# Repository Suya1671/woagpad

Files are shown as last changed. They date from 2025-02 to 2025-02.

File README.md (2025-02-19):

# The Woagpad

## A macropad of all time

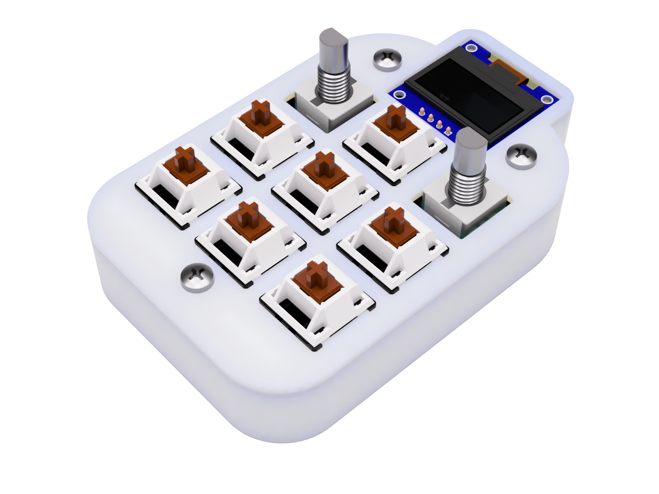
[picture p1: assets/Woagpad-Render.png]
Woagpad


The woagpad is a board I decided to create because a macropad
kinda just sounds fun. I really also wanted the rotary encoders
to be able to change volume and control media playback (although RMK doesn't support it yet. Eventually:tm:).

## Features

- **Rust based firmware**: Through the power of [RMK](https://haobogu.github.io/rmk), the firmware is written in 100% Rust. Crab gaming :crab:
  - [VIAL](https://get.vial.today/) support OOTB
- **128x64 OLED Display**: Display whatever the hell you want*
- **2 EC11 Rotary Encoders**: Control your volume or scroll through pages with these*
- **3x3 key matrix**: Keypad, macro, media controls, whatever the hell you want. You have 9 keys to mess around with (this includes the push buttons on the rotary encoders)

*The default rmk firmware does not support OLED display or rotary encoders yet.
Once those are implemented, the firmware will be updated to support them.
Write your own firmware to take advantage of these features!

## Design

### PCB
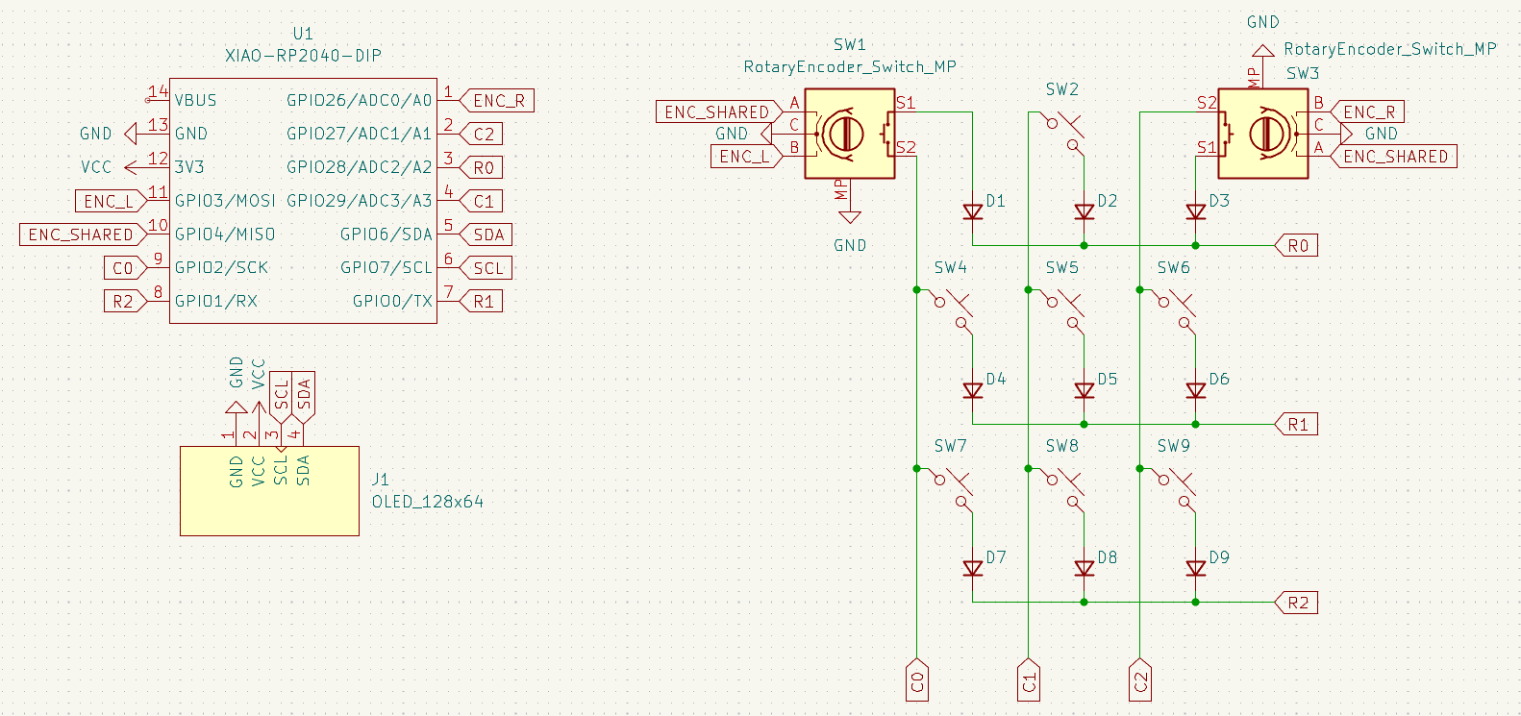
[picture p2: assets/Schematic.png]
Schematic


Bog standard PCB Schematic for a macropad.
This is actually my first design that uses a matrix
and an OLED display so that's fun.

Also yes, 2 encoders can share a pin! Neat.

|Front|Back|
|---|---|
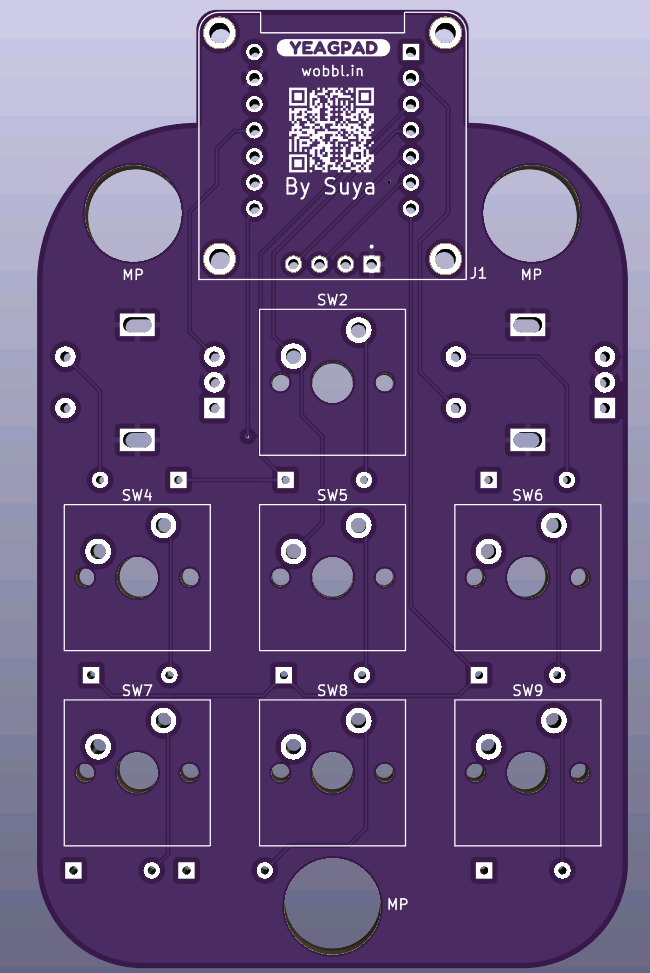
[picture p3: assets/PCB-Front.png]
PCB Front Design
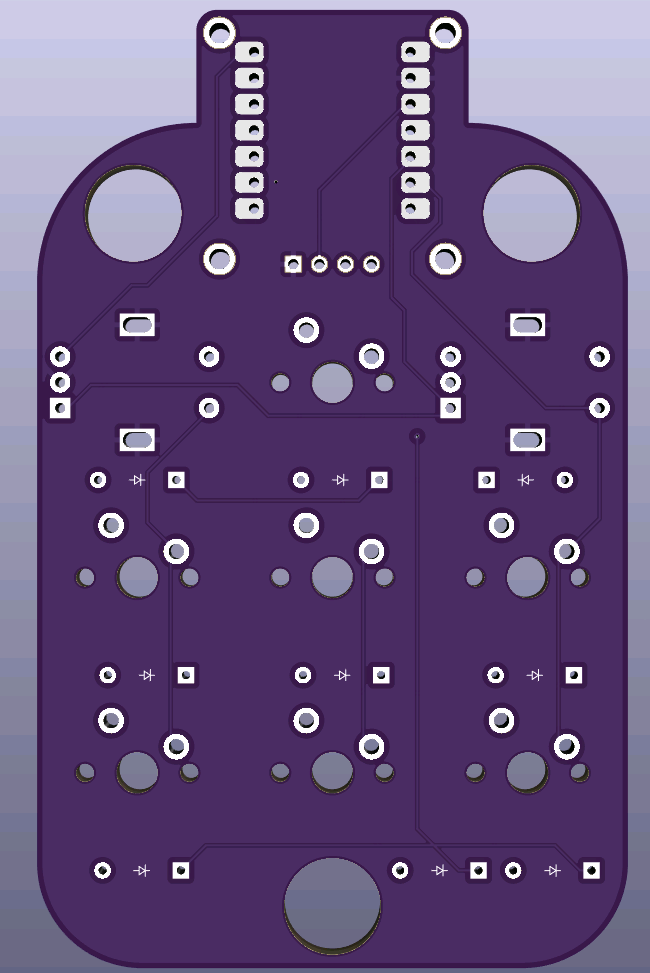
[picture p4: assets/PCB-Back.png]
PCB Back Design
|||

First PCB with actual mounting holes.
although in this case, the mounting holes are used
for mounting the top and bottom of the case.
See the case design for more details.

### Case
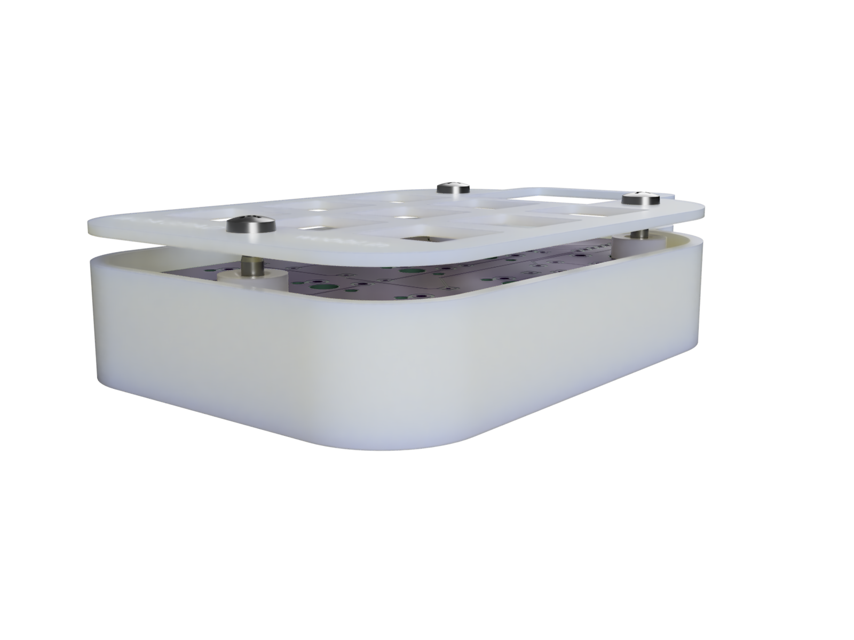
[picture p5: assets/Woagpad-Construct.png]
Case Design


Top integrated plate + frame. Bottom half with standoffs
for heat inserts to screw the two halves together.

Also yes, the encoder holes are slightly larger than the encoders.
I have no idea how well they'll actually fit so I decided for
more tolerance than normal. It'll be fine... right?

### BOM
- 1x PCB
  - see production/gerber.zip
- 1x Case
  - see production/Top.step
  - see production/Bottom.step
- 7X Cherry MX Switches
- 7X DSA Keycaps
- 2X Rotary Encoders
- 9X 1N4148 Diodes
- 3X M3x5mx4mm Heatset inserts
- 3X M3x16mm Bolts
- 1x XIAO RP2040
- 1x 0.91" 128x64 OLED Display

## Extras
First time using [RMK](https://haobogu.github.io/rmk) for firmware. It was WAY easier compared to other firmware options.
Highly reccomend if you don't need additional features.

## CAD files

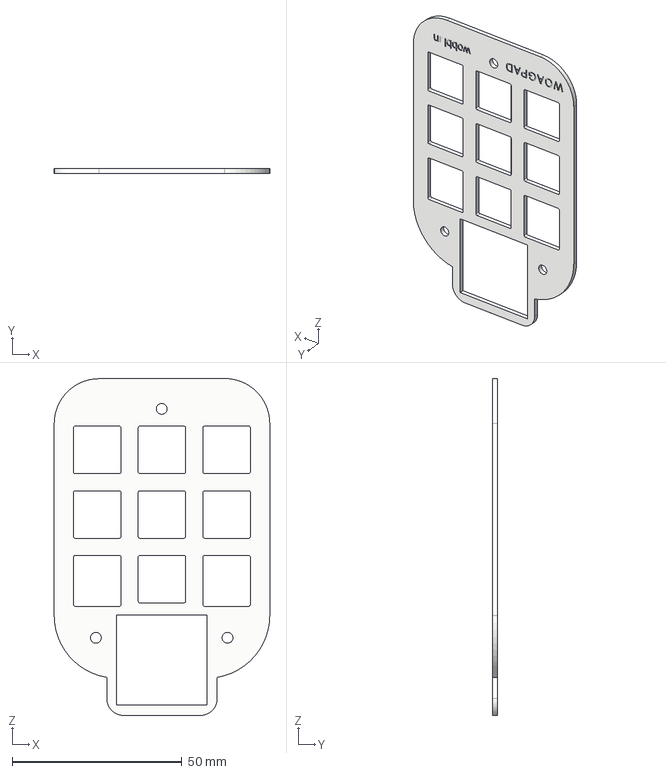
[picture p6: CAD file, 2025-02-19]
CAD/Top.step
63.5 x 1.50 x 99.3 mm

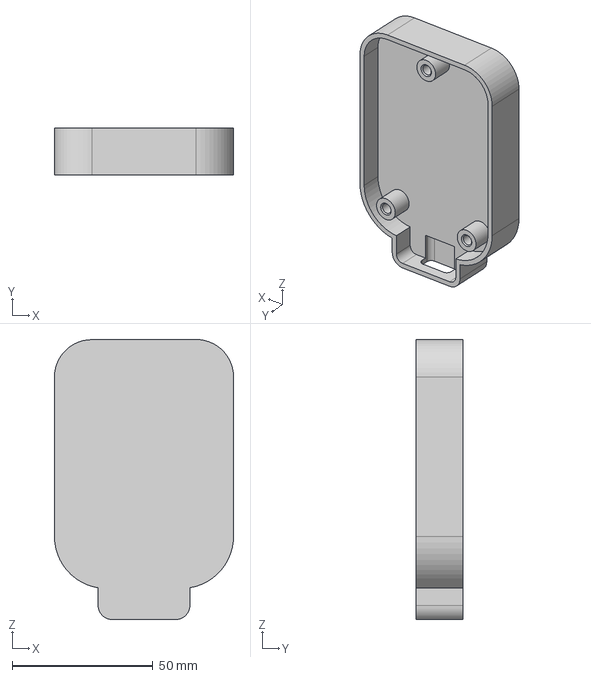
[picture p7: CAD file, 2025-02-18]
production/Bottom.step
63.5 x 16.5 x 99.3 mm

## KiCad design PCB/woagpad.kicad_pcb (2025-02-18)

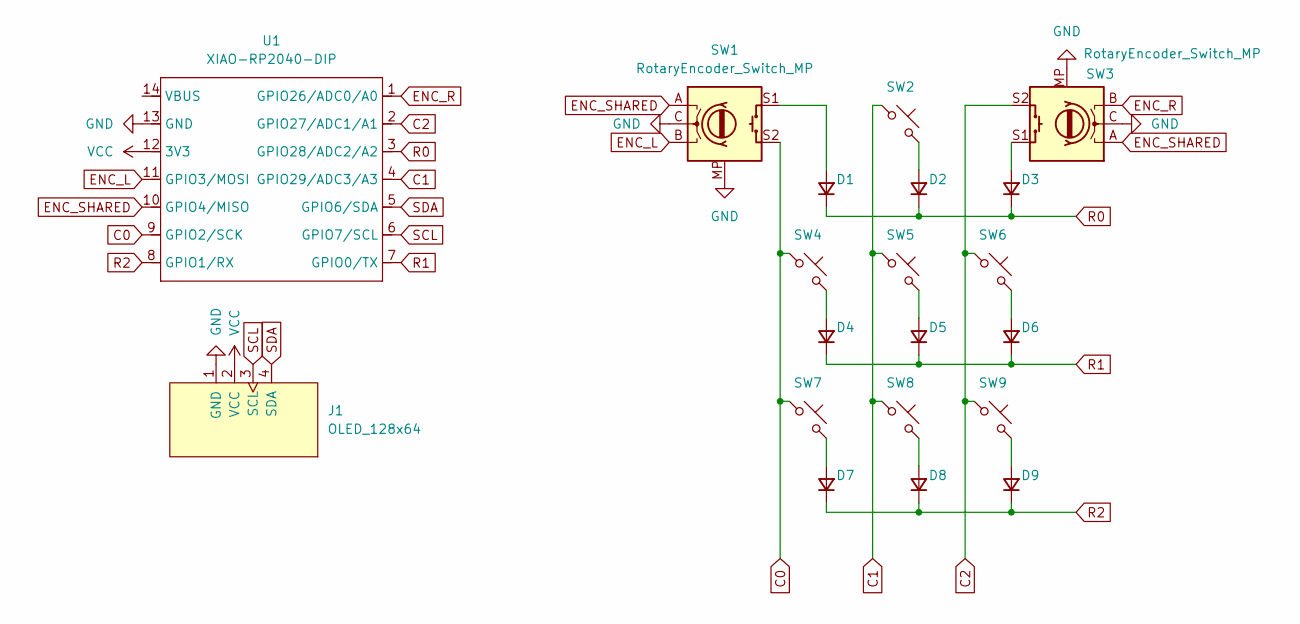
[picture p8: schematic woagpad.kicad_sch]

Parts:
D1, D2, D3, D4, D5, D6, D7, D8, D9: D; Diode_DO-35
J1: OLED_128x64; MODULE_DM-OLED096-636
SW1, SW3: RotaryEncoder_Switch_MP; Encoder_EC11_MX
SW2, SW4, SW5, SW6, SW7, SW8, SW9: SW_Push; MX_PCB
U1: XIAO-RP2040-DIP; Seeed_XIAO_RP2040

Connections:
C0: SW1.S2, SW4.1, SW7.1, U1.9 (GPIO2/SCK)
C1: SW2.1, SW5.1, SW8.1, U1.4 (GPIO29/ADC3/A3)
C2: SW3.S2, SW6.1, SW9.1, U1.2 (GPIO27/ADC1/A1)
ENC_L: SW1.B, U1.11 (GPIO3/MOSI)
ENC_R: SW3.B, U1.1 (GPIO26/ADC0/A0)
ENC_SHARED: SW1.A, SW3.A, U1.10 (GPIO4/MISO)
GND: J1.1 (GND), SW1.C, SW1.MP, SW3.C, SW3.MP, U1.13 (GND)
unnamed: D1.2 (A), SW1.S1
unnamed: D2.2 (A), SW2.2
unnamed: D3.2 (A), SW3.S1
unnamed: D4.2 (A), SW4.2
unnamed: D5.2 (A), SW5.2
unnamed: D6.2 (A), SW6.2
unnamed: D7.2 (A), SW7.2
unnamed: D8.2 (A), SW8.2
unnamed: D9.2 (A), SW9.2
R0: D1.1 (K), D2.1 (K), D3.1 (K), U1.3 (GPIO28/ADC2/A2)
R1: D4.1 (K), D5.1 (K), D6.1 (K), U1.7 (GPIO0/TX)
R2: D7.1 (K), D8.1 (K), D9.1 (K), U1.8 (GPIO1/RX)
SCL: J1.3 (SCL), U1.6 (GPIO7/SCL)
SDA: J1.4 (SDA), U1.5 (GPIO6/SDA)
VCC: J1.2 (VCC), U1.12 (3V3)

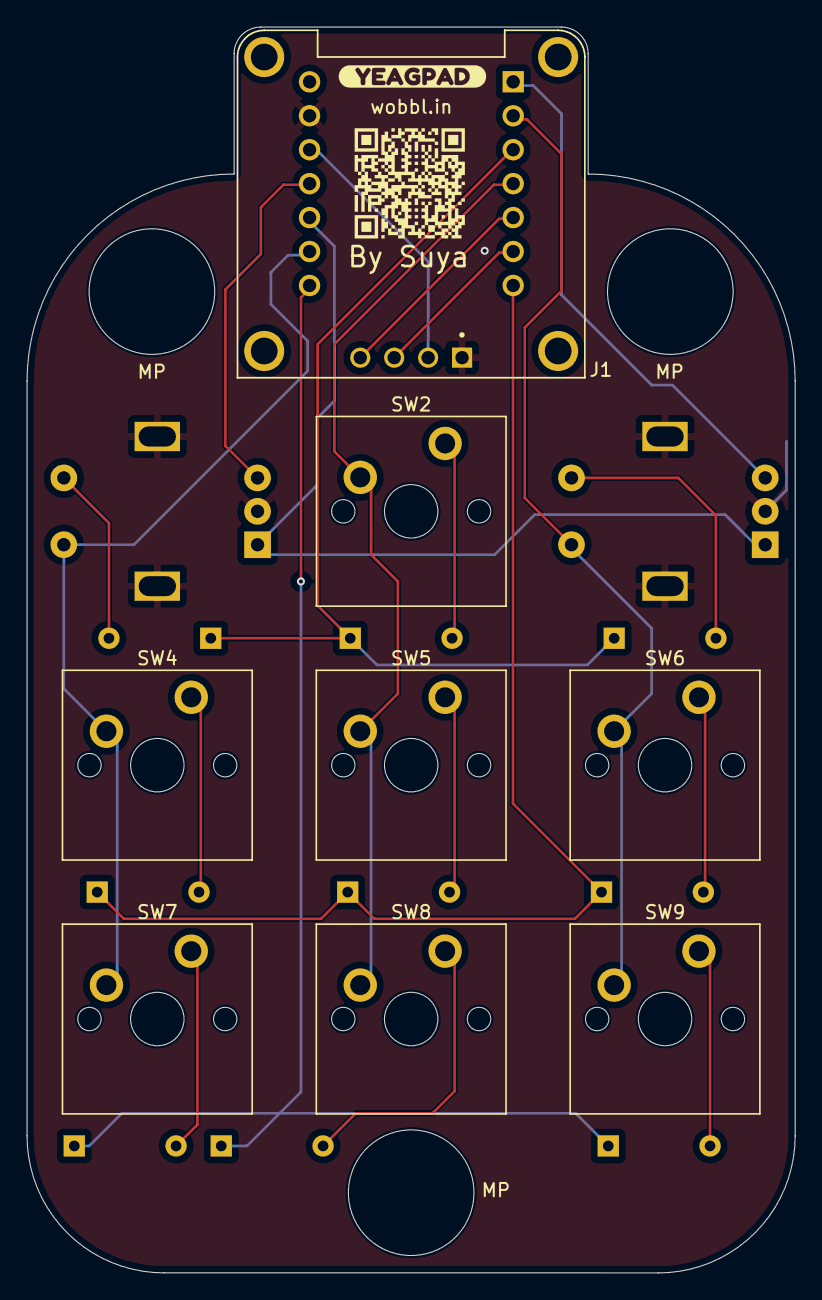
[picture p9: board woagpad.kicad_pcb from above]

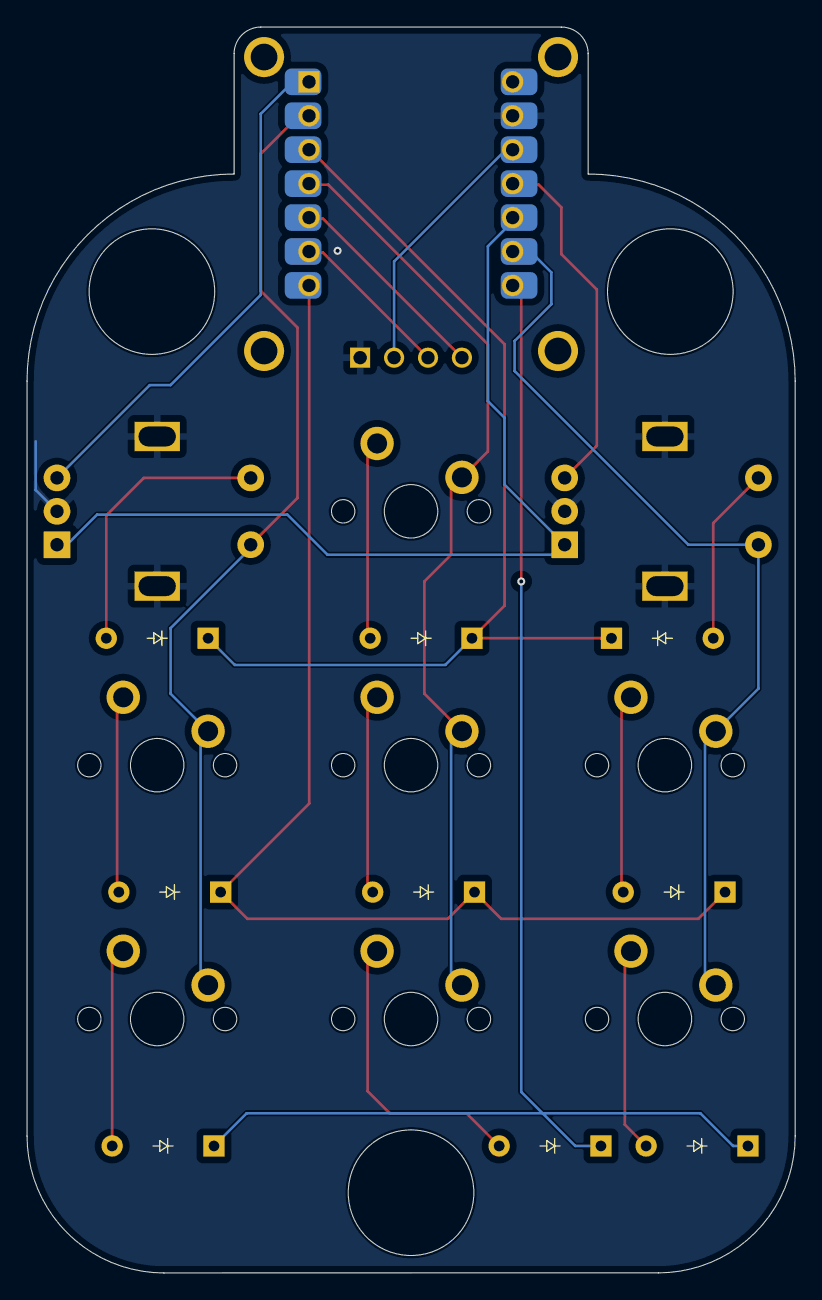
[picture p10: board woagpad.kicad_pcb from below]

Board: 2 copper layers, 57.5 x 93.2 mm, 22 parts (10 on the bottom side), 22 nets.

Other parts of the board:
QR*****: WobblQR
kibuzzard-67AA371A: G***; kibuzzard-67AA371A

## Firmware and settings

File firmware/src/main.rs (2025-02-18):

#![no_main]
#![no_std]

#[macro_use]
mod keymap;
#[macro_use]
mod macros;
mod vial;

use defmt::*;
use defmt_rtt as _;
use embassy_executor::Spawner;
use embassy_rp::{
    bind_interrupts,
    flash::{Async, Flash},
    gpio::{AnyPin, Input, Output},
    peripherals::USB,
    usb::{Driver, InterruptHandler},
    Peripheral,
};
// use embassy_rp::flash::Blocking;
use panic_probe as _;
use rmk::{
    config::{KeyboardUsbConfig, RmkConfig, VialConfig},
    input_device::{rotary_encoder::RotaryEncoder, InputDevice},
    run_devices, run_rmk, run_rmk_with_async_flash,
};
use vial::{VIAL_KEYBOARD_DEF, VIAL_KEYBOARD_ID};

bind_interrupts!(struct Irqs {
    USBCTRL_IRQ => InterruptHandler<USB>;
});

const FLASH_SIZE: usize = 2 * 1024 * 1024;

#[embassy_executor::main]
async fn main(spawner: Spawner) {
    info!("RMK start!");
    // Initialize peripherals
    let p = embassy_rp::init(Default::default());

    // Create the usb driver, from the HAL
    let driver = Driver::new(p.USB, Irqs);

    // Pin config
    let (input_pins, output_pins) = config_matrix_pins_rp!(peripherals: p, input: [PIN_2, PIN_29, PIN_27], output: [PIN_28, PIN_0, PIN_1]);

    // Use internal flash to emulate eeprom
    // Both blocking and async flash are support, use different API
    // let flash = Flash::<_, Blocking, FLASH_SIZE>::new_blocking(p.FLASH);
    let flash = Flash::<_, Async, FLASH_SIZE>::new(p.FLASH, p.DMA_CH0);

    let keyboard_usb_config = KeyboardUsbConfig {
        vid: 0x4c4b,
        pid: 0x4643,
        manufacturer: "woagpad",
        product_name: "woagpad",
        serial_number: "vial:f64c2b3c:000001",
    };

    let vial_config = VialConfig::new(VIAL_KEYBOARD_ID, VIAL_KEYBOARD_DEF);

    let keyboard_config = RmkConfig {
        usb_config: keyboard_usb_config,
        vial_config,
        ..Default::default()
    };

    let mut pin_4 = AnyPin::from(p.PIN_4).into_ref();
    let pin_shared = Input::new(&mut pin_4, embassy_rp::gpio::Pull::Up);
    let pin_left_b = Input::new(AnyPin::from(p.PIN_3), embassy_rp::gpio::Pull::Up);
    let pin_right_b = Input::new(AnyPin::from(p.PIN_26), embassy_rp::gpio::Pull::Up);
    let mut left_encoder = RotaryEncoder::new(pin_shared, pin_left_b, 0);
    // TODO: Implement right encoder (currently, the pin cannot be shared like this)
    // let mut right_encoder = RotaryEncoder::new(pin_shared, pin_right_b, 1);

    // Start serving
    // Use `run_rmk` for blocking flash
    embassy_futures::join::join(
        run_rmk_with_async_flash(
            input_pins,
            output_pins,
            driver,
            flash,
            &mut keymap::get_default_keymap(),
            keyboard_config,
            spawner,
        ),
        // note: encoders aren't implemented yet, so this does basically nothing for now /shrug
        run_devices!(left_encoder),
        // run_devices!(left_encoder, right_encoder),
    )
    .await;
}

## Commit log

2025-02-01 feat: initial commit
    [woagpad.kicad_pcb, woagpad.kicad_sch]
2025-02-02 feat: finish schematic
    [woagpad.kicad_pcb, woagpad.kicad_sch]
2025-02-13 feat: woagpad V0.1 PCB done
    [woagpad.kicad_pcb, woagpad.kicad_sch]
2025-02-18 feat: case and firmware
    [Bottom.step, Top.step, woagpad.kicad_pcb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]
2025-02-18 wip: work on production files for hackpad submission
    [Bottom.step, Top.step]
2025-02-19 feat: first submission draft
    [Top.step]
